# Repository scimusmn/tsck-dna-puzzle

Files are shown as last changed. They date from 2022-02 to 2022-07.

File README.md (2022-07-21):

tsck-dna-puzzle
===============

This repository contains software and hardware files for the [DNA Puzzle for TSCK].

The puzzle consists of a steel double-helix with embedded RFID readers, individual
"nucleotide" pieces containing RFID tags, and a large stele containing an LED
disk that displays an "eye", whose appearance changes based on the arrangement
of nucleotides in the helix.

software
--------

The software is split into three pieces: 

* the RFID readers, which collect UART data from the reader modules and store it
  to be served via I2C (stored in `arduino/rfid-attiny`);
* the main controller, which reads the stored data on the RFID readers via I2C,
  updates the internal genome data, and then transmits it to the lighting controller
  (stored in `arduino/controller`); and
* the lighting controller, which received genome data from the main controller and 
  updates the LEDs as appropriate (stored in `arduino/lighting-controller`).

hardware
--------

There are two broad categories of hardware included in this repository:

* CAD files (mostly laser-cut pieces) stored in `laser-cutter`; and
* electronics (both schematics and PCB layouts) stored in `electronics`.

[DNA Puzzle for TSCK]: https://drive.google.com/drive/folders/1d9PLsUjKqNwdjKIzH2Ln1TuXTCMuD0Dc

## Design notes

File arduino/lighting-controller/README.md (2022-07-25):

lighting-controller
===================

This sketch takes serial input dictating the current genome from the Mega and then updates the Soya DotStar array to match.

Protocol
--------

This sketch uses stele-style packets at 115200 baud for communication. It only accepts one key: "genome", the value of which should be a six-character string containing only 'G', 'A', 'T', or 'C'. This string will then be processed into a unique eye color layout.

Overview
--------

Almost all of the objects are contained in the global namespace and are managed by the main sketch more or less directly. The LEDs use the [FastLED library] and are defined by the main sketch before being passed by reference to the `disk` object.

  * `SerialController.h` - `arduino-base` boilerplate for stele packet communication
  * `SoyaDisk.h` - defines the `Ring` and `Disk` classes used for controlling the LEDs
  * `lighting-controller.ino` - main sketch entry point

[FastLED library]: http://fastled.io/

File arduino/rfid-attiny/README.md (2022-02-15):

rfid-attiny
===========

This program is intended for ATTiny84 chips monitoring ID-2LA, ID-12LA, or ID-20LA 125kHz RFID reader modules.

setup
-----

Tested using the [ATTinyCore] board pack.

Obtain a fresh ATTiny84. Open the sketch in the Arduino IDE, and select the following under the "Tools" menu:

* Board: ATtiny24/44/84(a) (No bootloader)
* Chip: ATtiny84a
* Clock Source: 8 MHz (internal)
* Pin Mapping: clockwise
* Programmer: USBTinyISP (ATTinyCore) SLOW

Then click `Tools > Burn Bootloader` (I know, I know, it says "no bootloader", but this is needed to set the clock speed).

Set the `ADDRESS` macro to whatever you'd like the device address to be, and then click `Sketch > Upload Using Programmer`. Done!

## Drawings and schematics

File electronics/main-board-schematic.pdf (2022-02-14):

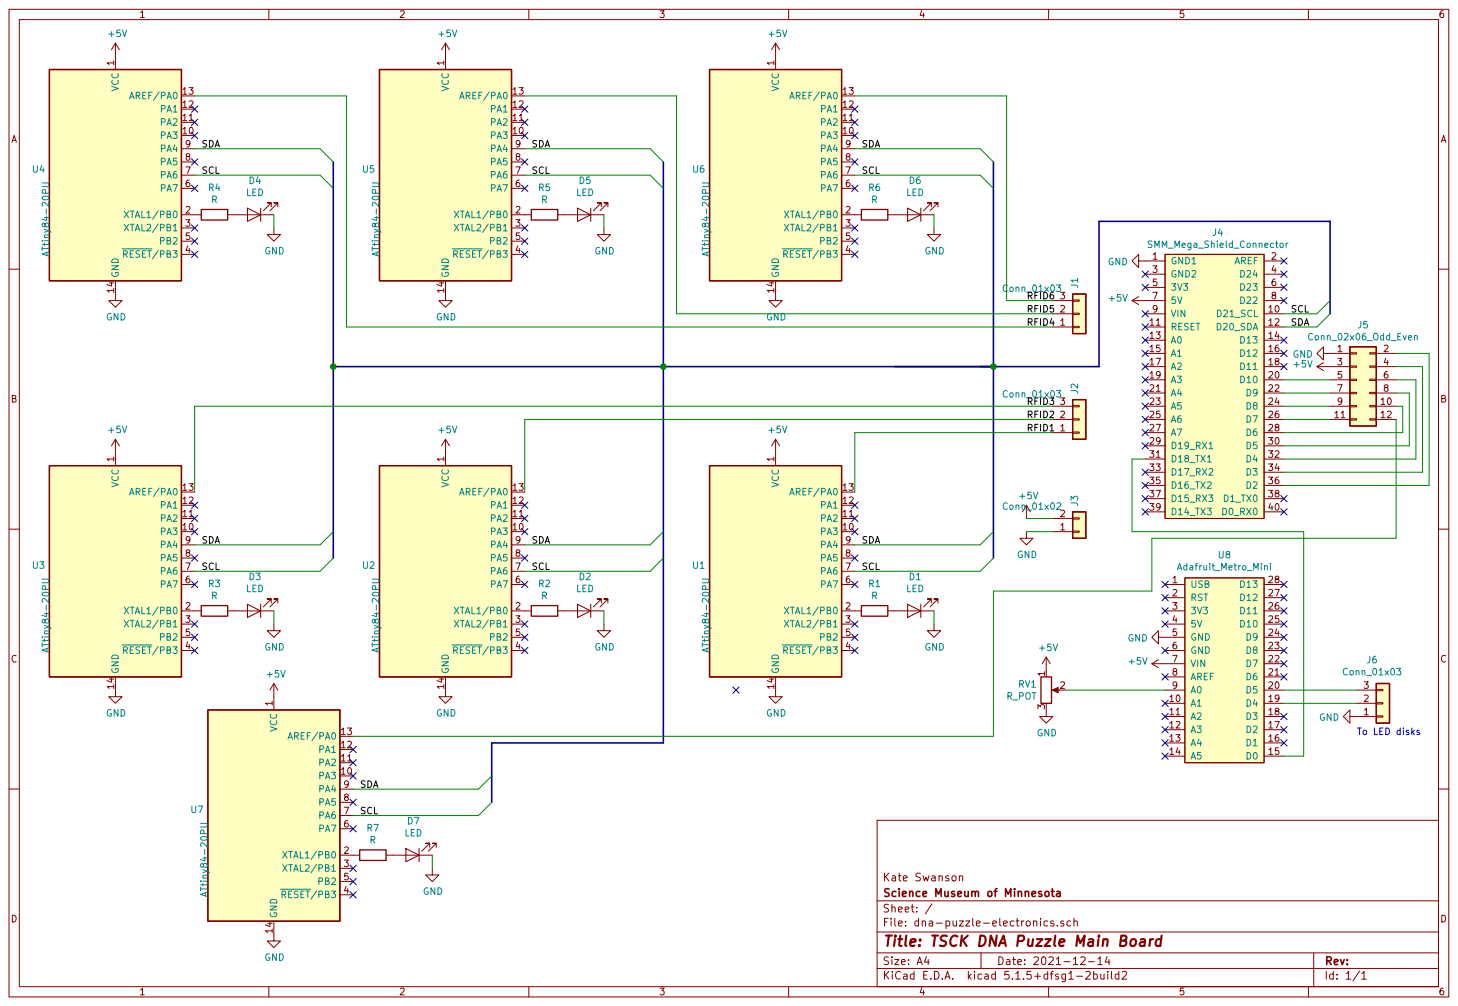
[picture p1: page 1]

File: dna-puzzle-electronics.sch Sheet: / Science Museum of Minnesota Kate Swanson GND

Id: 1/1 Title: TSCK DNA Puzzle Main Board

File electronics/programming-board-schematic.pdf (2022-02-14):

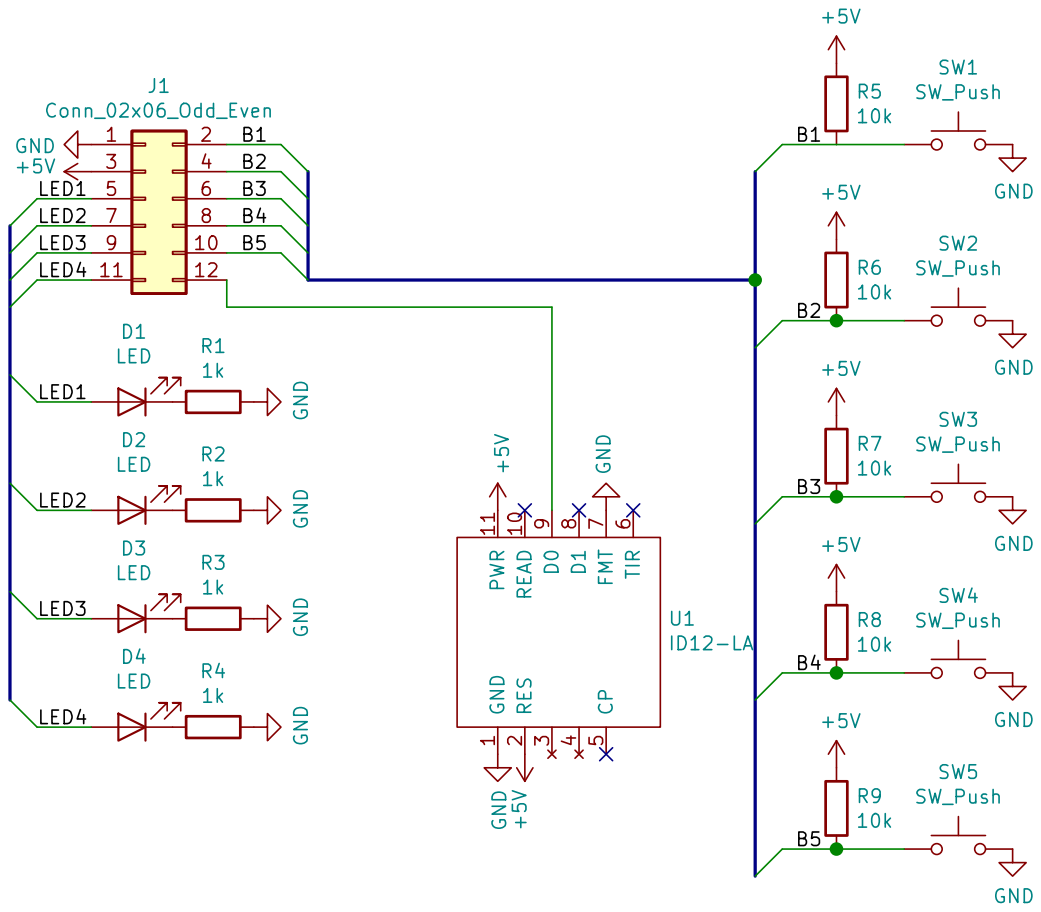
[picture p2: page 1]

File: programming-board.sch Sheet: / D2

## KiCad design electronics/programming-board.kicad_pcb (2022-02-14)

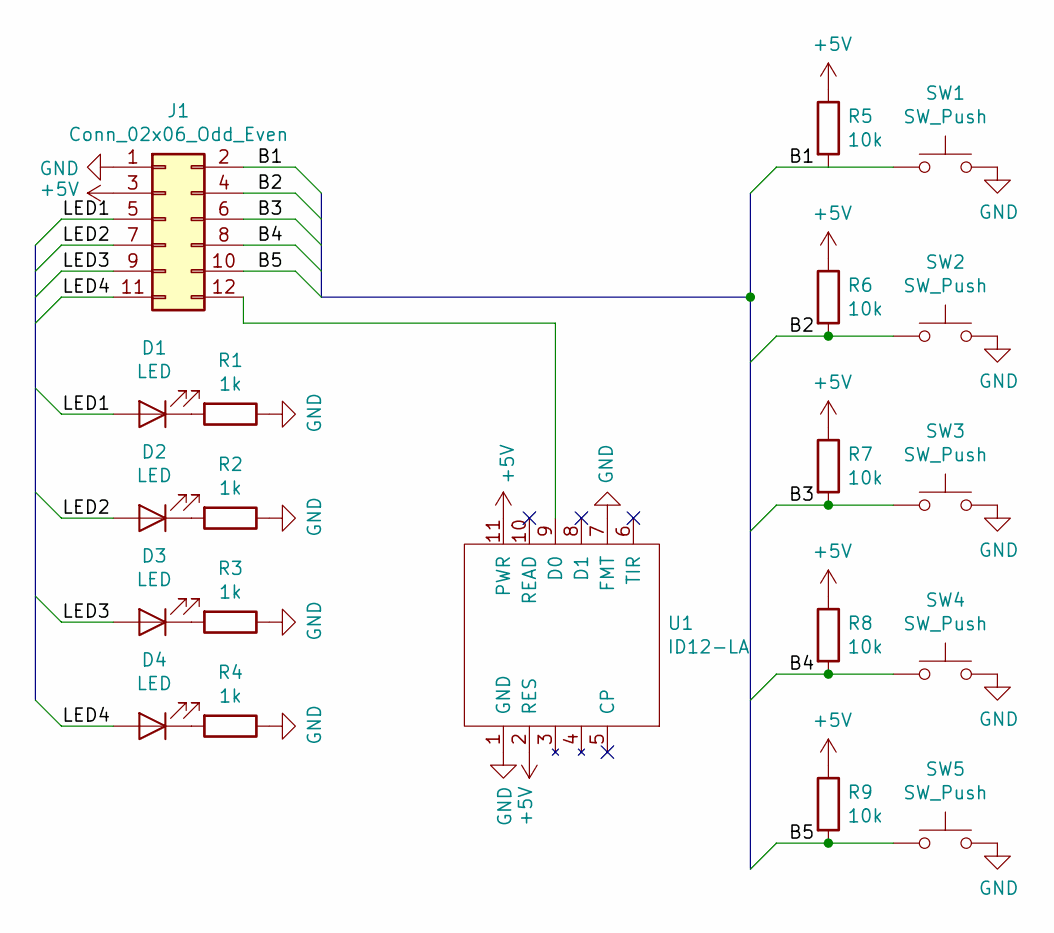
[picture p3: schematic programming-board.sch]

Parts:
D1, D2, D3, D4: LED; LED_D3.0mm
J1: Conn_02x06_Odd_Even; PinHeader_2x06_P2.54mm_Vertical
R1, R2, R3, R4: 1k; R_Axial_DIN0207_L6.3mm_D2.5mm_P10.16mm_Horizontal
R5, R6, R7, R8, R9: 10k; R_Axial_DIN0207_L6.3mm_D2.5mm_P10.16mm_Horizontal
SW1, SW2, SW3, SW4, SW5: SW_Push; SW_PUSH_6mm_H4.3mm
U1: ID12-LA; ID-12LA

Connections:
+5V: J1.3, R5.1, R6.1, R7.1, R8.1, R9.1, U1.2 (RES), U1.11 (PWR)
/B1: J1.2, R5.2, SW1.1
/B2: J1.4, R6.2, SW2.1
/B3: J1.6, R7.2, SW3.1
/B4: J1.8, R8.2, SW4.1
/B5: J1.10, R9.2, SW5.1
/LED1: D1.2 (A), J1.5
/LED2: D2.2 (A), J1.7
/LED3: D3.2 (A), J1.9
/LED4: D4.2 (A), J1.11
GND: J1.1, R1.1, R2.1, R3.1, R4.1, SW1.2, SW2.2, SW3.2, SW4.2, SW5.2, U1.1 (GND), U1.7 (FMT)
unnamed: D1.1 (K), R1.2
unnamed: D2.1 (K), R2.2
unnamed: D3.1 (K), R3.2
unnamed: D4.1 (K), R4.2
unnamed: J1.12, U1.9 (D0)

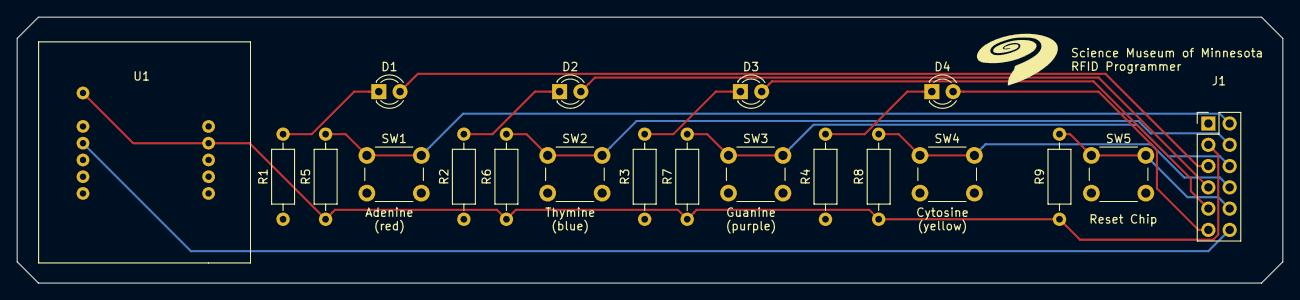
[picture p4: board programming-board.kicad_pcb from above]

Board: 2 copper layers, 151.1 x 31.8 mm, 20 parts (0 on the bottom side), 16 nets.

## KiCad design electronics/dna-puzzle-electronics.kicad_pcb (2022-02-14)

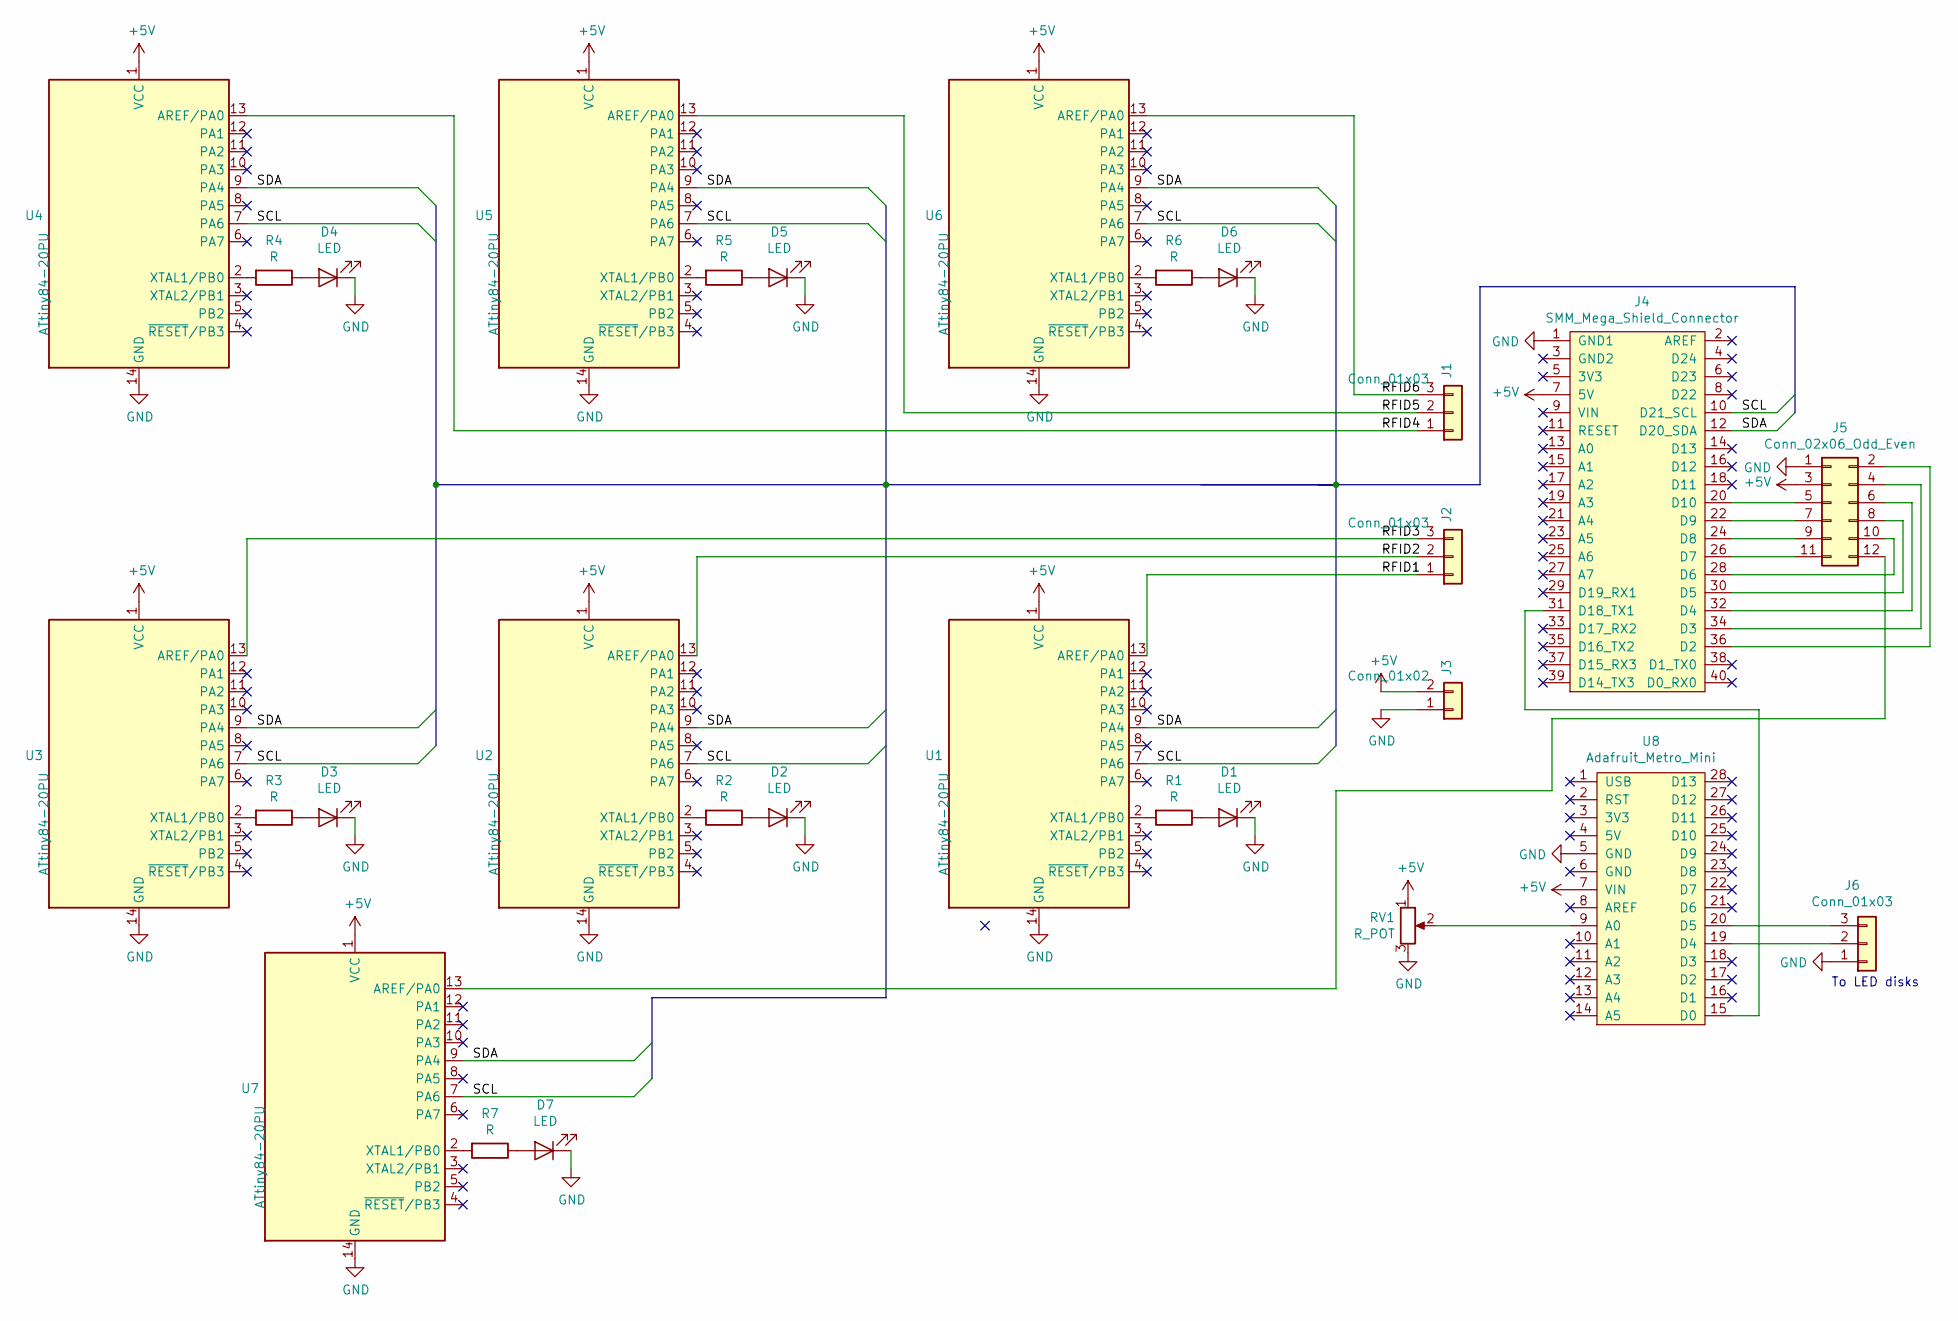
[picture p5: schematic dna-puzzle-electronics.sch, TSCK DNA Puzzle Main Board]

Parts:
D1, D2, D3, D4, D5, D6, D7: LED; LED_D3.0mm
J1, J2, J6: Conn_01x03; Molex_KK-254_AE-6410-03A_1x03_P2.54mm_Vertical
J3: Conn_01x02; Molex_KK-254_AE-6410-02A_1x02_P2.54mm_Vertical
J4: SMM_Mega_Shield_Connector; PinHeader_2x20_P2.54mm_Vertical
J5: Conn_02x06_Odd_Even; PinHeader_2x06_P2.54mm_Vertical
R1, R2, R3, R4, R5, R6, R7: R; R_Axial_DIN0207_L6.3mm_D2.5mm_P10.16mm_Horizontal
RV1: R_POT; Potentiometer_ACP_CA6-H2,5_Horizontal
U1, U2, U3, U4, U5, U6, U7: ATtiny84-20PU; DIP-14_W7.62mm
U8: Adafruit_Metro_Mini; Metro-Mini

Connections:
+5V: J3.2, J4.7 (5V), J5.3, RV1.1, U1.1 (VCC), U2.1 (VCC), U3.1 (VCC), U4.1 (VCC), U5.1 (VCC), U6.1 (VCC), U7.1 (VCC), U8.7 (VIN)
/RFID1: J2.1, U1.13 (AREF/PA0)
/RFID2: J2.2, U2.13 (AREF/PA0)
/RFID3: J2.3, U3.13 (AREF/PA0)
/RFID4: J1.1, U4.13 (AREF/PA0)
/RFID5: J1.2, U5.13 (AREF/PA0)
/RFID6: J1.3, U6.13 (AREF/PA0)
/SCL: J4.10 (D21_SCL), U1.7 (PA6), U2.7 (PA6), U3.7 (PA6), U4.7 (PA6), U5.7 (PA6), U6.7 (PA6), U7.7 (PA6)
/SDA: J4.12 (D20_SDA), U1.9 (PA4), U2.9 (PA4), U3.9 (PA4), U4.9 (PA4), U5.9 (PA4), U6.9 (PA4), U7.9 (PA4)
GND: D1.1 (K), D2.1 (K), D3.1 (K), D4.1 (K), D5.1 (K), D6.1 (K), D7.1 (K), J3.1, J4.1 (GND1), J5.1, J6.1, RV1.3, U1.14 (GND), U2.14 (GND), U3.14 (GND), U4.14 (GND), U5.14 (GND), U6.14 (GND), U7.14 (GND), U8.5 (GND)
unnamed: D1.2 (A), R1.1
unnamed: D2.2 (A), R2.1
unnamed: D3.2 (A), R3.1
unnamed: D4.2 (A), R4.1
unnamed: D5.2 (A), R5.1
unnamed: D6.2 (A), R6.1
unnamed: D7.2 (A), R7.1
unnamed: J4.20 (D10), J5.5
unnamed: J4.22 (D9), J5.7
unnamed: J4.24 (D8), J5.9
unnamed: J4.26 (D7), J5.11
unnamed: J4.28 (D6), J5.10
unnamed: J4.30 (D5), J5.8
unnamed: J4.31 (D18_TX1), U8.15 (D0)
unnamed: J4.32 (D4), J5.6
unnamed: J4.34 (D3), J5.4
unnamed: J4.36 (D2), J5.2
unnamed: J5.12, U7.13 (AREF/PA0)
unnamed: J6.2, U8.19 (D4)
unnamed: J6.3, U8.20 (D5)
unnamed: R1.2, U1.2 (XTAL1/PB0)
unnamed: R2.2, U2.2 (XTAL1/PB0)
unnamed: R3.2, U3.2 (XTAL1/PB0)
unnamed: R4.2, U4.2 (XTAL1/PB0)
unnamed: R5.2, U5.2 (XTAL1/PB0)
unnamed: R6.2, U6.2 (XTAL1/PB0)
unnamed: R7.2, U7.2 (XTAL1/PB0)
unnamed: RV1.2, U8.9 (A0)

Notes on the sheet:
To LED disks

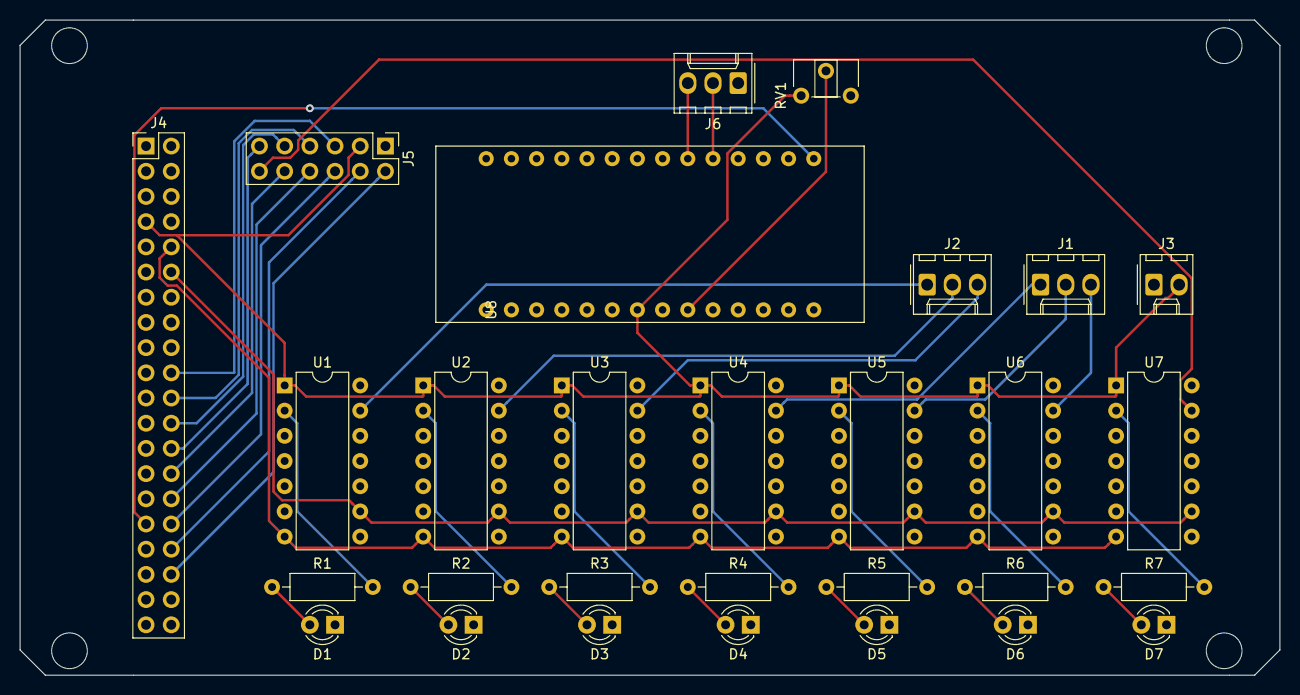
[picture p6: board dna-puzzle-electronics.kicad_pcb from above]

Board: 2 copper layers, 127.0 x 66.0 mm, 29 parts (0 on the bottom side), 38 nets.

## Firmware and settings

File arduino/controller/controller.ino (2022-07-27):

/* Copyright (c) 2022 Science Museum of Minnesota
 * 
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
 * THE SOFTWARE IS PROVIDED “AS IS”, WITHOUT WARRANTY OF ANY KIND, EXPRESS
 * OR IMPLIED, INCLUDING BUT NOT LIMITED TO THE WARRANTIES OF MERCHANTABILITY,
 * FITNESS FOR A PARTICULAR PURPOSE AND NONINFRINGEMENT. IN NO EVENT SHALL
 * THE AUTHORS OR COPYRIGHT HOLDERS BE LIABLE FOR ANY CLAIM, DAMAGES OR OTHER
 * LIABILITY, WHETHER IN AN ACTION OF CONTRACT, TORT OR OTHERWISE, ARISING
 * FROM, OUT OF OR IN CONNECTION WITH THE SOFTWARE OR THE USE OR OTHER DEALINGS
 * IN THE SOFTWARE.
 */

#include "SerialController.h"
#include "Button.h"
#include "Rfid/Controller.h"
#include "Rfid/Tag.h"
#include "Queue.h"
#include "ProgrammerLeds.h"
#include "SmmTimeoutTimer.h"

using namespace smm;

// serial interfaces
SerialController<> serial;


// the RFID controller
#define NUM_RFID_READERS 6
#define MAX_RFID_TAGS 48
#define NUM_CATEGORIES 4
#define LED 13

RfidController<
    NUM_RFID_READERS,
    MAX_RFID_TAGS,
    NUM_CATEGORIES
    > rfid;

#define LEDA 10
#define LEDT 9
#define LEDG 8
#define LEDC 7

ProgrammerLeds leds(LEDA, LEDT, LEDG, LEDC);

// genome
char genome[7] = "GGGGGG";
unsigned long rfidUpdateTime;


// rfid category handlers
void sendGenome() {
    serial.send("genome", genome);
    Serial1.print("{genome:");
    Serial1.print(genome);
    Serial1.println("}");
}

void handleKnownTag(byte addr, char base) {
   const int reader = addr - 0x70;
   if (reader == 6) {
      // teaching reader
      leds.show(base);
   }
   else {
      // helix reader
      genome[reader] = base;
      sendGenome();
   }
}

void onReadG(byte addr, RfidTag& tag) {
   handleKnownTag(addr, 'G');
}
void onReadC(byte addr, RfidTag& tag) {
   handleKnownTag(addr, 'C');
}
void onReadT(byte addr, RfidTag& tag) {
   handleKnownTag(addr, 'T');
}
void onReadA(byte addr, RfidTag& tag) {
   handleKnownTag(addr, 'A');
}

RfidTag unknownTag;
bool teaching = false;

void onReadUnknown(byte address, RfidTag& tag) {
   serial.send("read-unknown", tag.toString().c_str());
   if (address != 0x76) {
      serial.send("read-unknown-on", address);
   }
   else {
      unknownTag = tag;
      teaching = true;
      leds.flash();
   }
}


// buttons
Button teachA(2);
Button teachT(3);
Button teachG(4);
Button teachC(5);
Button teachUndo(6);
SmmTimeoutTimer forgetAllTimeout(5000);

void updateButtons() {
    teachG.update();
    teachC.update();
    teachT.update();
    teachA.update();
    teachUndo.update();
}

void teach(byte category) {
    if (!teaching)
		return;
    serial.send("teaching-tag", unknownTag.toString().c_str());
    serial.send("teaching-as", category);
    rfid.teachTag(unknownTag, category);
    teaching = false;
    leds.show(category);
}


// ~~~~~~~~~~~~~~~~~~~~~~~~~~~~~~~~

void setup() {
    pinMode(LED, OUTPUT);

    serial.setup();
    Serial1.begin(115200);

    rfid.setup();
    rfid.addReader(0x70);
    rfid.addReader(0x71);
    rfid.addReader(0x72);
    rfid.addReader(0x73);
    rfid.addReader(0x74);
    rfid.addReader(0x75);
    rfid.addReader(0x76);

    rfid.onRead('G', onReadG);
    rfid.onRead('C', onReadC);
    rfid.onRead('T', onReadT);
    rfid.onRead('A', onReadA);
    rfid.onReadUnknown(onReadUnknown);

    rfid.onReadFailure([](byte addr) { serial.send("read-failure", addr); });

    rfidUpdateTime = millis() + 100;
    
    teachG.onPress([](void *d) { teach('G'); });
    teachC.onPress([](void *d) {teach('C'); });
    teachT.onPress([](void *d) { teach('T'); });
    teachA.onPress([](void *d) { teach('A'); });
    teachUndo.onPress([](void *d) {
    	forgetAllTimeout.start();
    });
    teachUndo.onRelease([](void *d) {
    	forgetAllTimeout.stop();
		rfid.forgetLastTag();
		leds.setAll(1);
		delay(50);
		leds.setAll(0);
	});

    serial.send("arduino-ready");
    serial.send("known-tags", (int) rfid.numKnownTags());
    rfid.dumpTags();
    rfid.testReaders();
}


void loop() {
    if (teaching)
	digitalWrite(LED, 1);
    else
	digitalWrite(LED, 0);
    
    serial.update();
    if (millis() > rfidUpdateTime) {
	rfidUpdateTime = millis() + 100;
	rfid.update();
    }

    if (forgetAllTimeout.triggered()) {
    	rfid.forgetEveryTag();
    	leds.setAll(1);
    	delay(50);
    	leds.setAll(0);
    }

    leds.update();
    updateButtons();
}

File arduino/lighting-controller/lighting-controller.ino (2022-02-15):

#include <FastLED.h>

#define LED_DATA 5
#define LED_CLOCK 4

#define MAX_KEY_LEN 8
#define MAX_VAL_LEN 7

#include "SerialController.h"
SerialController serialController;

#include "SoyaDisk.h"

Disk disk;
CRGB leds[SOYA_NUM_LEDS];

char genome[] = { 'A', 'A', 'A', 'A', 'A', 'A', 0 };

/*
CRGB colorA = CRGB(0xff, 0x00, 0x00); // #ff0000 (red)
CRGB colorT = CRGB(0x22, 0xca, 0xb1); // #22cab1 (cyan)
CRGB colorG = CRGB(0xa4, 0x00, 0xb1); // #a400b1 (purple)
CRGB colorC = CRGB(0xf4, 0xdc, 0x00); // #f4dc00 (yellow)
*/


CRGB colorA = CRGB(0x4a, 0x22, 0x1d); // #ff0000 (brown)
CRGB colorT = CRGB(0x2f, 0x82, 0x37); // #22cab1 (green)
CRGB colorG = CRGB(0x1c, 0x6d, 0x9c); // #a400b1 (blue)
CRGB colorC = CRGB(0xcb, 0xa0, 0x29); // #f4dc00 (yellow)


void printId(byte id[5]) {
    Serial.print("[ ");
    for(int i=0; i<6; i++) {
	Serial.print(id[i], HEX); Serial.print(" ");
    }
    Serial.println("]");
}

void processGenome(char *update) {
    int length = strlen(update);
    length = length < 6 ? length : 6;
    for (int i=0; i<length; i++)
	genome[i] = update[i];
    updateDiskFromGenome(disk);
    FastLED.show();
    serialController.sendMessage("update-genome", genome);
}

void setup() {
    serialController.setup(115200, false);
    serialController.sendMessage("begin-setup");

    serialController.sendMessage("allocate-memory");
    disk.setup(leds);
    serialController.sendMessage("setup leds");
    FastLED.addLeds<APA102, LED_DATA, LED_CLOCK, BGR>(leds, SOYA_NUM_LEDS);

    delay(100);
    serialController.sendMessage("add LEDs");
    processGenome("GATCGA");
    FastLED.show();

    serialController.sendMessage("finish-setup", 1);
    serialController.addCallback("genome", processGenome);
}

CRGB baseColor(char base) {
    switch(base) {
    case 'A':
	return colorA;
    case 'G':
	return colorG;
    case 'T':
	return colorT;
    case 'C':
	return colorC;
    default:
	return CRGB::Black;
    }
}

void updateDiskFromGenome(Disk& disk) {
    const int smallWedge = 21;
    const int largeWedge = 128;
    int offset = 0;

    for (int i=0; i<6; i++) {
	disk.wedge(offset, offset+smallWedge, baseColor(genome[i]));
	disk.wedge(offset + largeWedge, offset+largeWedge+smallWedge, baseColor(genome[i]));
	disk.wedge(offset + 2*largeWedge, offset+(2*largeWedge)+smallWedge, baseColor(genome[i]));
	offset += smallWedge;
    }

    for (int i=6; i<10; i++)
	disk[i].setAll(CRGB::Black);
}

void loop() {
    serialController.update();

    uint8_t brightness = analogRead(A0) >> 2;
    FastLED.setBrightness(dim8_raw(brightness));
}

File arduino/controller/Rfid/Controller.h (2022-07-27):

#pragma once

#ifdef UNIT_TEST
#include "../tests/FakeEEPROM.h"
#include "../tests/FakeWire.h"
#else
#include <EEPROM.h>
#include <Wire.h>
#endif

#include "../FixedSizeString.h"
#include "../LookupTable.h"
#include "Tag.h"

typedef unsigned char byte;

namespace smm {
    template<typename keyT, typename valT, unsigned int MAX_ENTRIES>
    class EEPROMLookupTable :
	public smm::LookupTable<keyT, valT, MAX_ENTRIES> {
    	public:
		void load() {
		    int numEntries = EEPROM[0];
		    if (numEntries == 255)
			// assume previously unwritten memory cell
			numEntries = 0;

		    if (numEntries > MAX_ENTRIES)
				// only read up to MAX_ENTRIES entries
				numEntries = MAX_ENTRIES;

		    for (int i=0; i<numEntries; i++)
				readEntry(i);

		}

		void save() {
		    EEPROM.update(0, this->size());
		    for (int i=0; i<this->size(); i++)
				saveEntry(i);
		}

		void undo() {
			if (this->m_numEntries == 0) return;
			this->m_numEntries -= 1;
		}

		void reset() {
			this->m_numEntries = 0;
		}

    	private:
		void readEntry(int index) {
		    const int entrySize = sizeof(keyT) + sizeof(valT);
		    int address = 1 + (index * entrySize);

		    keyT key;
		    unsigned char *b = (unsigned char *) &key;
		    for (int i=0; i<sizeof(keyT); i++) {
				*b = EEPROM[address+i];
				b++;
		    }
		    valT value;
		    b = (unsigned char *) &value;
		    for (int i=0; i<sizeof(valT); i++) {
				*b = EEPROM[address+sizeof(keyT)+i];
				b++;
		    }
		    this->add(key, value);
		}

		void saveEntry(int index) {
		    const int entrySize = sizeof(keyT) + sizeof(valT);
		    int address = 1 + (index * entrySize);

		    keyT key = this->key(index);
		    unsigned char *b = (unsigned char *) &key;
		    for (int i=0; i<sizeof(keyT); i++)
				EEPROM.update(address+i, *(b+i));

		    valT value = this->value(index);
		    b = (unsigned char *) &value;
		    for (int i=0; i<sizeof(valT); i++)
				EEPROM.update(address+sizeof(keyT)+i, *(b+i));
		}
    };


    // ~~~~~~~~~~~~~~~~~~~~~~~~~~~~~~~~

    typedef void (*readHandler)(byte, RfidTag&);

    #define MAX_READ_ATTEMPTS 3


    template<unsigned int MAX_READERS,
	     unsigned int MAX_TAGS,
	     unsigned int MAX_CATEGORIES>
    class RfidController {
    public:
	void setup() {
	    tags.load();
	    numReaders = 0;
	    Wire.begin();
	}
	void update() {
	    for (int i=0; i<numReaders; i++)
		updateReader(readers[i]);
	}

	void addReader(byte address) {
	    readers[numReaders] = address;
	    numReaders++;
	}
	void onRead(byte category, readHandler handler) {
	    handlers.add(category, handler);
	}
	void onReadUnknown(readHandler handler) {
	    unknownTagHandler = handler;
	}
	void onReadFailure(void (*handler)(byte address)) {
	    readFailHandler = handler;
	}
	void teachTag(RfidTag tag, byte category) {
	    tags.add(tag, category);
	    tags.save();
	}

	void forgetLastTag() {
	    if (tags.size() == 0)
		return;
		tags.undo();
		tags.save();
	}

	void forgetEveryTag() {
		tags.reset();
		tags.save();
	}

	size_t numKnownTags() {
	    return tags.size();
	}

	void dumpTags() {
	    for (int i=0; i<tags.size(); i++) {
		Serial.print(tags.key(i).toString().c_str());
		Serial.print(" -> ");
		Serial.println((char) tags.value(i));
	    }
	}

	void testReaders() {
	    RfidTag tag;
	    for (int i=0; i<numReaders; i++) {
		byte address = readers[i];
		bool ok = loadTag(address, tag);
		Serial.print("reader 0x");
		Serial.print(address, HEX);
		if (ok)
		    Serial.println(": OK");
		else {
		    Serial.println(": FAIL");
		    Wire.requestFrom(address, 6);
		    Serial.print("requested 6 bytes, received ");
		    Serial.println(Wire.available());
		    while (Wire.available())
			Serial.println(Wire.read(), HEX);
		}
	    }
	}
    private:
	EEPROMLookupTable<RfidTag, byte, MAX_TAGS> tags;
	LookupTable<byte, readHandler, MAX_CATEGORIES> handlers;
	readHandler unknownTagHandler;
	void (*readFailHandler)(byte);
	int numReaders;
	byte readers[MAX_READERS];

	bool loadTag(byte address, RfidTag& tag) {
	    Wire.requestFrom(address, 6);
	    bool tagIsEmpty = true;
	    for (int i=0; i<5; i++) {
		if (!(Wire.available()))
		    return false; // not enough address bytes
		tag.tagData[i] = Wire.read();
	    }

	    if (!(Wire.available()))
		return false; // no checksum byte
	    byte checksum = Wire.read();
	    if (tag.checksum() != checksum)
		return false; // bad checksum
	    return true;
	}

	bool tagIsEmpty(RfidTag& tag) {
	    if (tag.tagData[0] != 255)
		return false;
	    if (tag.tagData[1] != 255)
		return false;
	    if (tag.tagData[2] != 255)
		return false;
	    if (tag.tagData[3] != 255)
		return false;
	    if (tag.tagData[4] != 255)
		return false;
	    return true;
	}

	void clearTag(byte address) {
	    Wire.beginTransmission(address);
	    Wire.write(0x54); // CLEAR TAG command
	    Wire.endTransmission();
	}

	void updateReader(byte address) {
	    RfidTag tag;
	    for (int i=0; i<MAX_READ_ATTEMPTS; i++) {
		bool success = loadTag(address, tag);
		bool empty = tagIsEmpty(tag);
		if (success && !empty) {
		    processTag(address, tag);
		    break;
		}
		else if (!success && !empty) {
		    if (readFailHandler != nullptr)
		    readFailHandler(address);//*/
		}

	    }
	    // success or failure, clear the reader
	    clearTag(address);
	}

	void processTag(byte address, RfidTag& tag) {
	    byte *category = tags[tag];
	    if (category != nullptr) {
		readHandler *handler = handlers[*category];
		if (handler != nullptr)
		    (*handler)(address, tag);
	    }
	    else { // unknown tag
		if (unknownTagHandler != nullptr)
		    unknownTagHandler(address, tag);
	    }
	}
    };
}

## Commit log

2021-09-28 add board templates and update lighting code
2022-01-24 refactor: move all arduino code into arduino/ and rename appropriately
2022-01-24 add electronic hardware files
    [dna-puzzle-electronics-B_Cu.gbl, dna-puzzle-electronics-B_Mask.gbs, dna-puzzle-electronics-B_Paste.gbp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]
2022-01-24 move laser cut files into single folder
2022-01-24 rename: dna-puzzle-electronics -> electronics
    [dna-puzzle-electronics-B_Cu.gbl, dna-puzzle-electronics-B_Mask.gbs, dna-puzzle-electronics-B_Paste.gbp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]
2022-01-25 implement controller's programmer board
2022-02-15 switch Reader sketch to unix line endings
2022-02-15 add README.md and fix timing
    [rfid-attiny.ino]
2022-02-15 fix lighting clock/data pins
    [controller.ino, lighting-controller.ino]
